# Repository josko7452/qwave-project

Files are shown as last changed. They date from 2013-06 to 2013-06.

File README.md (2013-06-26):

QWave-project
=============

Working FPGA development board with USB 2.0 interface and DSO module (125MHz analog dual channel with 16bit logic analyzer)
Although hadware was implemented it is not thoroughly tested, especially analog part is not intented as ready to build kit, it is inteded for hackers and people who are wiling to play around to get it working.

# Project parts
* **hardware** design sources of FPGA developement board and DSO module in eagle
* **firmware** sources of FPGA firmware in MyHDL and translated VHDL Xinix ISE project directory
* **software** sources of Qt based DSO sampling software

# Preview
## FPGA dev board and DSO module (dimensions 10x4cm):
-FPGA board and DSO module
## Software
[Screenshot gallery](http://imgur.com/a/RICwH#0)

#Schematics
[Link to PDF](https://www.dropbox.com/sh/cy4ldah24slzdpa/zRzbHfkyo1)

#Details:
## FPGA board:
### What works:
* FPGA programming and 3.3V logic interface and FT245 Sync interface (USB 2.0 speed)

### TODO:
* Direct USB programming of FPGA flash - need to use JTAG and Xilinx USB Platform Cable for programming

## Analog (DSO module) board:
### What works:
* DSO functionality

### What was not tested:
* Logic analyzer on anything faster than few kHz
* Compensation of analog input

### TODO:
* Eliminating noise on analog circuits

## Firmware
### TODO:
* Fix trigger
* Add selectable trigger holdoff
* Do not insert trigger in single-shot mode

## Software
### TODO:
* Better performance
* Make more user-friendly selection of trigger
* Add exact voltage meter

## For hackers/ee guys and developers:
See HACKING.md

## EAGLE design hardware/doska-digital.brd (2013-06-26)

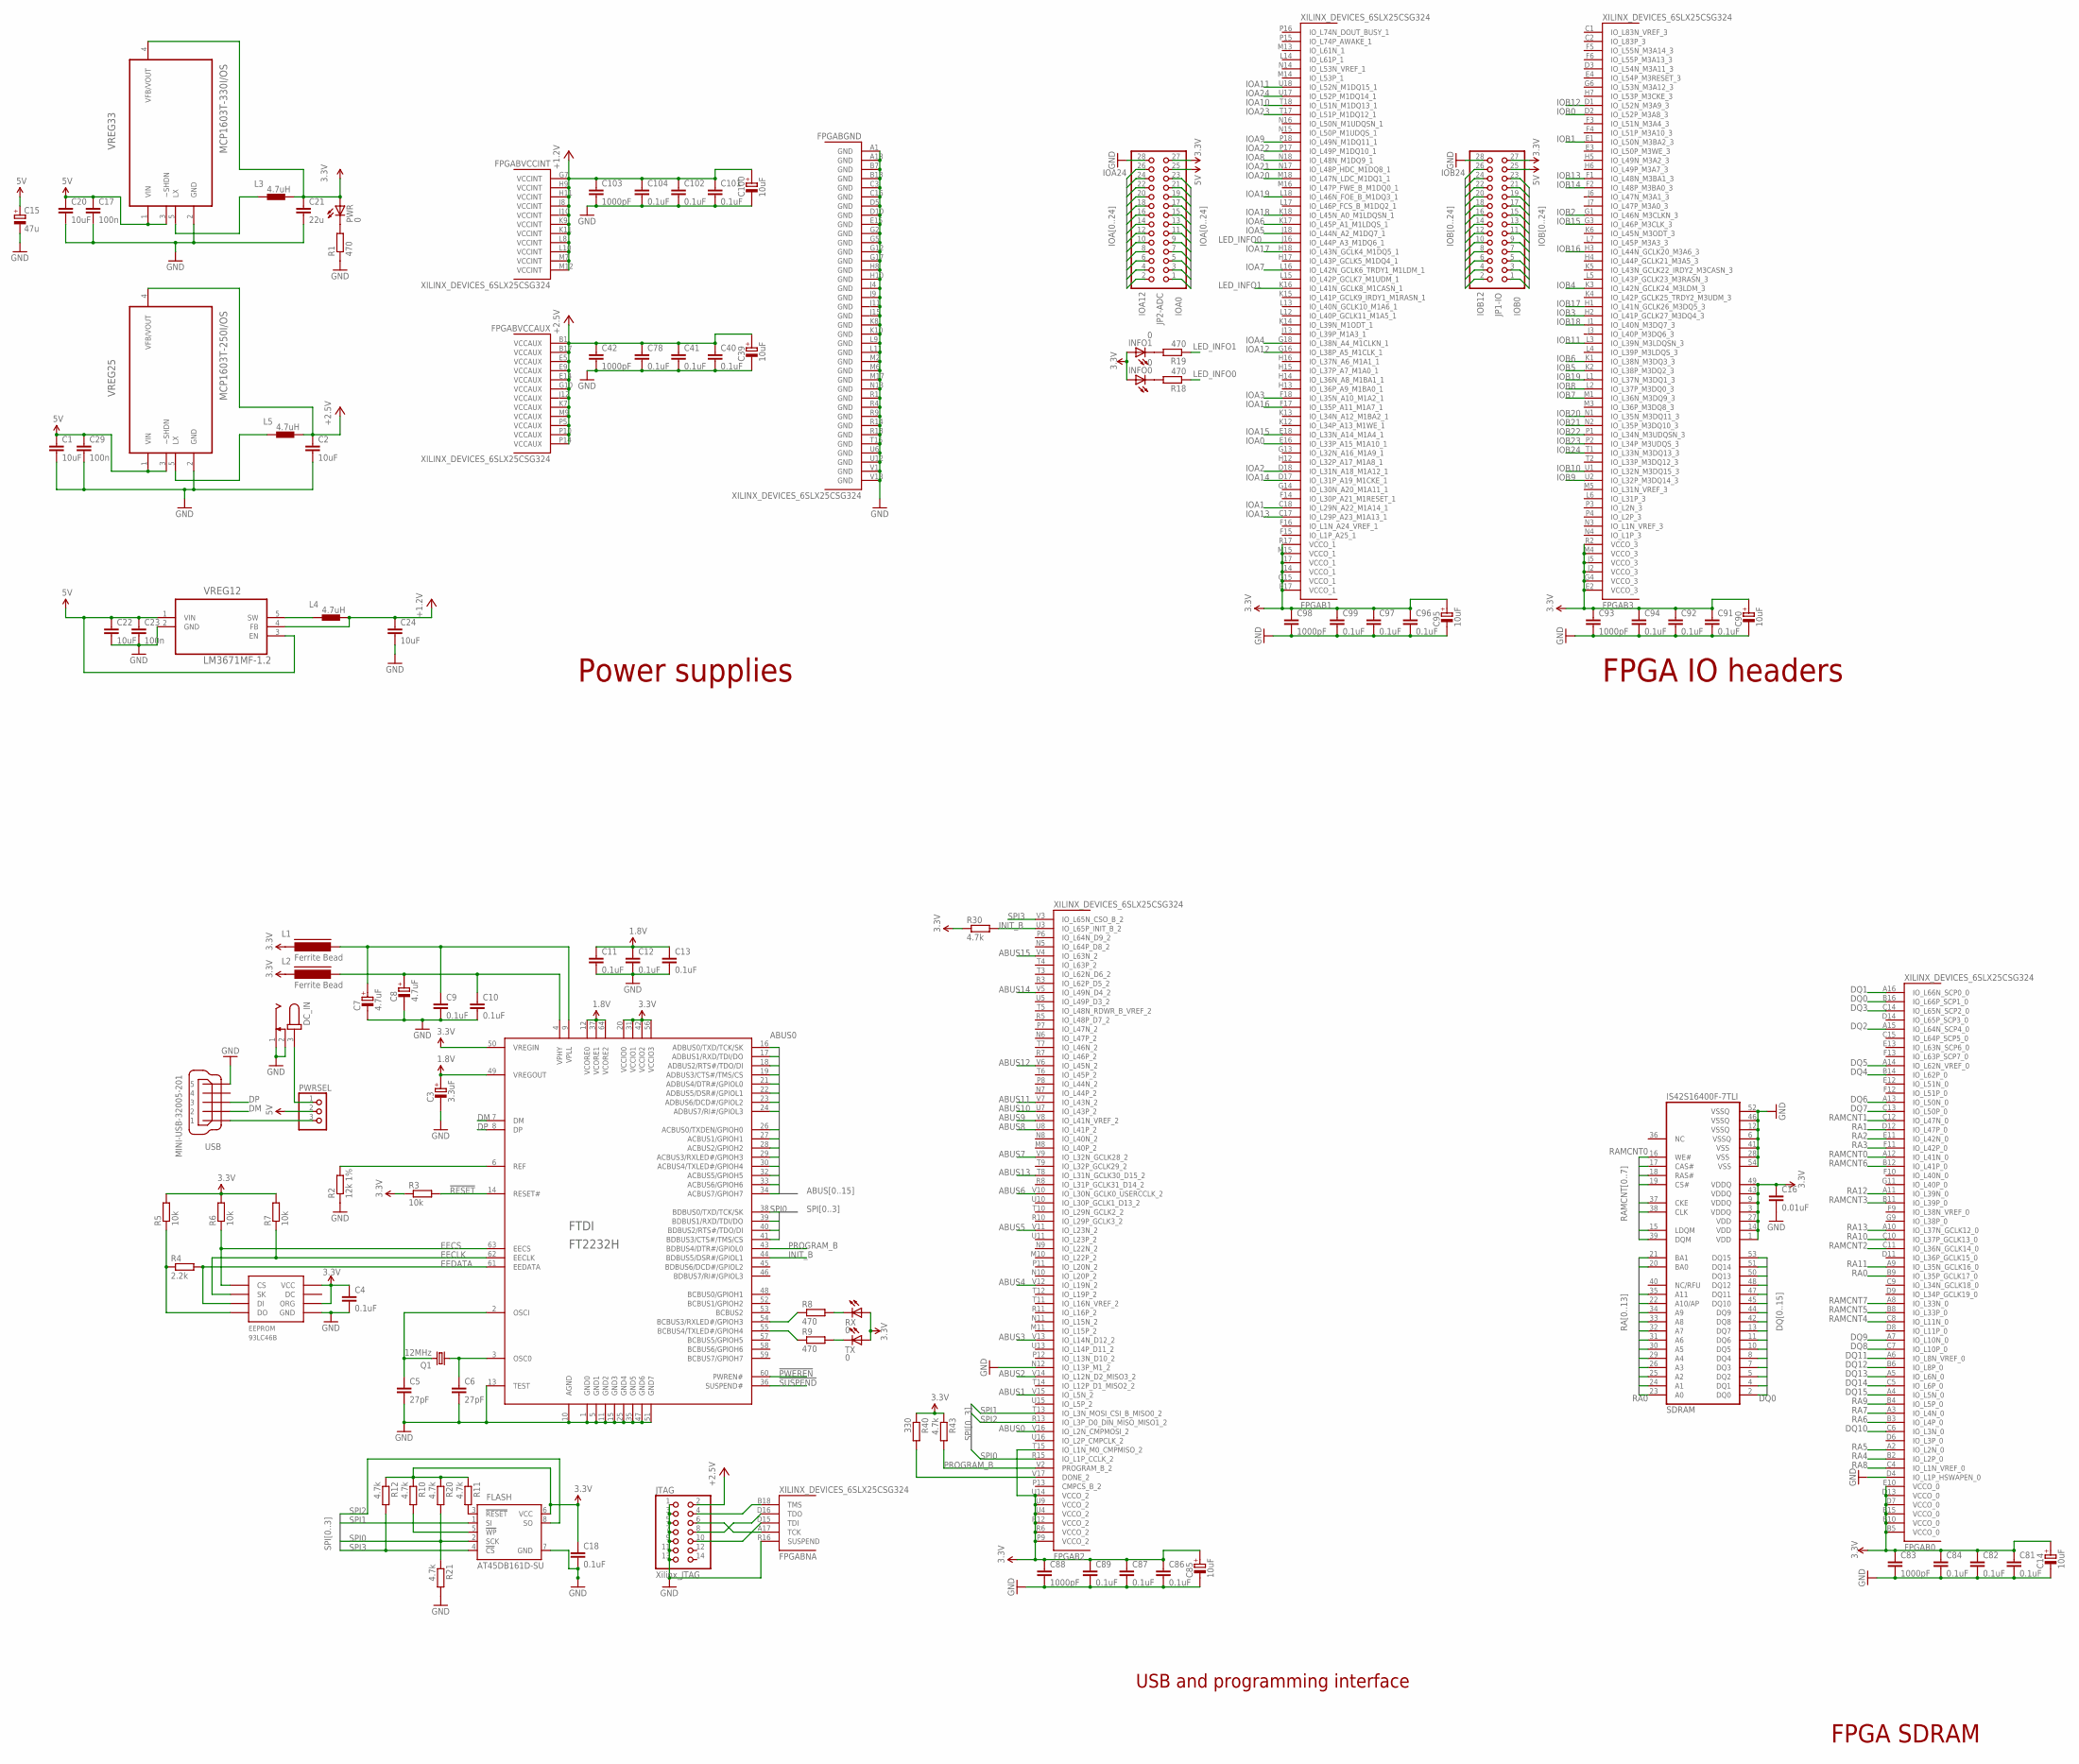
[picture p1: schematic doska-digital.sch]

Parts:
C1, C2, C20, C22, C24: 10uF; C805
C3: 3.3uF; CAPMP3216X180N
C4, C13, C18: 0.1uF; C805
C5, C6: 27pF; C805
C7, C8: 4.7uF; CAPMP3216X180N
C9, C10, C11, C12, C40, C41, C78, C81, C82, C84, C86, C87, C89, C91, C92, C94, C96, C97, C99, C101, C102, C104: 0.1uF; C603
C14, C39, C85, C90, C95, C100: 10uF; CAPMP3216X180N
C15: 47u; RCL_E2-5
C16: 0.01uF; C805
C17, C23, C29: 100n; C805
C21: 22u; C805
C42, C83, C88, C93, C98, C103: 1000pF; C603
DC_IN: CON-JACK_JACK-PLUG1; CON-JACK_SPC4078
EEPROM: 93LC46B; SOIC8
FLASH: AT45DB161D-SU; 8S2
FPGA: XILINX_DEVICES_6SLX25CSG324; XILINX_DEVICES_CS324
FTDI: FT2232H; LQFP64
INFO0, INFO1: 0; CHIPLED_1206
JP1-IO, JP2-ADC: PINHEAD_PINHD-2X14; PINHEAD_2X14
JTAG: Xilinx_JTAG; PINHEAD_2X07
L1, L2: Ferrite Bead; FB805
L3, L4, L5: 4.7uH; SMT43
PWR: 0; CHIPLED_1206
PWRSEL: PINHEAD_PINHD-1X3; PINHEAD_1X03
Q1: 12MHz; CTS406
R1, R8, R9, R18, R19: 470; R805
R2: 12k 1%; R603
R3, R5, R6, R7: 10k; R805
R4: 2.2k; R805
R10, R11, R12: 4.7k; R805
R20, R21, R30, R43: 4.7k; R603
R40: 330; R603
RX: 0; CHIPLED_1206
SDRAM: IS42S16400F-7TLI; TSOP54
TX: 0; CHIPLED_1206
USB: MINI-USB-32005-201; 32005-201
VREG12: LM3671MF-1.2; SOT95P284X122-5N
VREG25: MCP1603T-250I/OS; SOT95P280X110-5N
VREG33: MCP1603T-330I/OS; SOT95P280X110-5N

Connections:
1.8V: C3.+, C11.1, C12.1, C13.1, FTDI.12 (VCORE0), FTDI.37 (VCORE1), FTDI.49 (VREGOUT), FTDI.64 (VCORE2)
3.3V: C4.1, C14.+, C16.1, C18.1, C21.1, C81.1, C82.1, C83.1, C84.1, C85.+, C86.1, C87.1, C88.1, C89.1, C90.+, C91.1, C92.1, C93.1, C94.1, C95.+, C96.1, C97.1, C98.1, C99.1, EEPROM.6 (ORG), EEPROM.8 (VCC), FLASH.6 (VCC), FPGA.B5 (VCCO_0), FPGA.B10 (VCCO_0), FPGA.B15 (VCCO_0), FPGA.D7 (VCCO_0), FPGA.D13 (VCCO_0), FPGA.E2 (VCCO_3), FPGA.E10 (VCCO_0), FPGA.E17 (VCCO_1), FPGA.G4 (VCCO_3), FPGA.G15 (VCCO_1), FPGA.J2 (VCCO_3), FPGA.J5 (VCCO_3), FPGA.J14 (VCCO_1), FPGA.J17 (VCCO_1), FPGA.M4 (VCCO_3), FPGA.M15 (VCCO_1), FPGA.P9 (VCCO_2), FPGA.R2 (VCCO_3), FPGA.R6 (VCCO_2), FPGA.R12 (VCCO_2), FPGA.R17 (VCCO_1), FPGA.T15 (IO_L1N_M0_CMPMISO_2), FPGA.U4 (VCCO_2), FPGA.U9 (VCCO_2), FPGA.U14 (VCCO_2), FTDI.20 (VCCIO0), FTDI.31 (VCCIO1), FTDI.42 (VCCIO2), FTDI.50 (VREGIN), FTDI.56 (VCCIO3), INFO0.A, INFO1.A, JP1-IO.27, JP2-ADC.27, L1.2, L2.2, L3.P$1 (1), PWR.A, R3.1, R5.2, R6.2, R7.2, R10.1, R11.1, R12.1, R20.1, R30.1, R40.1, R43.1, RX.A, SDRAM.1 (VDD), SDRAM.3 (VDDQ), SDRAM.9 (VDDQ), SDRAM.14 (VDD), SDRAM.27 (VDD), SDRAM.43 (VDDQ), SDRAM.49 (VDDQ), TX.A, VREG33.4 (VFB/VOUT)
5V: C1.1, C15.+, C17.1, C20.1, C22.1, C23.1, C29.1, JP1-IO.25, JP2-ADC.25, PWRSEL.2, VREG12.1 (VIN), VREG12.3 (EN), VREG25.1 (VIN), VREG25.3 (~SHDN), VREG33.1 (VIN), VREG33.3 (~SHDN)
!PWEREN: FTDI.60 (PWREN#)
!RESET: FTDI.14 (RESET#), R3.2
!SUSPEND: FTDI.36 (SUSPEND#)
+1.2V: C24.1, C100.+, C101.1, C102.1, C103.1, C104.1, FPGA.G7 (VCCINT), FPGA.H9 (VCCINT), FPGA.H11 (VCCINT), FPGA.J8 (VCCINT), FPGA.J10 (VCCINT), FPGA.K9 (VCCINT), FPGA.K11 (VCCINT), FPGA.L8 (VCCINT), FPGA.L10 (VCCINT), FPGA.M7 (VCCINT), FPGA.M12 (VCCINT), L4.P$1 (1), VREG12.4 (FB)
+2.5V: C2.1, C39.+, C40.1, C41.1, C42.1, C78.1, FPGA.B1 (VCCAUX), FPGA.B17 (VCCAUX), FPGA.E5 (VCCAUX), FPGA.E9 (VCCAUX), FPGA.E14 (VCCAUX), FPGA.G10 (VCCAUX), FPGA.J12 (VCCAUX), FPGA.K7 (VCCAUX), FPGA.M9 (VCCAUX), FPGA.P5 (VCCAUX), FPGA.P10 (VCCAUX), FPGA.P14 (VCCAUX), JTAG.2, L5.P$1 (1), VREG25.4 (VFB/VOUT)
ABUS0: FPGA.V16 (IO_L2N_CMPMOSI_2), FTDI.16 (ADBUS0/TXD/TCK/SK)
ABUS1: FPGA.V15 (IO_L5N_2), FTDI.17 (ADBUS1/RXD/TDI/DO)
ABUS2: FPGA.V14 (IO_L12N_D2_MISO3_2), FTDI.18 (ADBUS2/RTS#/TDO/DI)
ABUS3: FPGA.V13 (IO_L14N_D12_2), FTDI.19 (ADBUS3/CTS#/TMS/CS)
ABUS4: FPGA.V12 (IO_L19N_2), FTDI.21 (ADBUS4/DTR#/GPIOL0)
ABUS5: FPGA.V11 (IO_L23N_2), FTDI.22 (ADBUS5/DSR#/GPIOL1)
ABUS6: FPGA.V10 (IO_L30N_GCLK0_USERCCLK_2), FTDI.23 (ADBUS6/DCD#/GPIOL2)
ABUS7: FPGA.V9 (IO_L32N_GCLK28_2), FTDI.24 (ADBUS7/RI#/GPIOL3)
ABUS8: FPGA.U8 (IO_L41P_2), FTDI.26 (ACBUS0/TXDEN/GPIOH0)
ABUS9: FPGA.V8 (IO_L41N_VREF_2), FTDI.27 (ACBUS1/GPIOH1)
ABUS10: FPGA.U7 (IO_L43P_2), FTDI.28 (ACBUS2/GPIOH2)
ABUS11: FPGA.V7 (IO_L43N_2), FTDI.29 (ACBUS3/RXLED#/GPIOH3)
ABUS12: FPGA.V6 (IO_L45N_2), FTDI.30 (ACBUS4/TXLED#/GPIOH4)
ABUS13: FPGA.T8 (IO_L31N_GCLK30_D15_2), FTDI.32 (ACBUS5/GPIOH5)
ABUS14: FPGA.V5 (IO_L49N_D4_2), FTDI.33 (ACBUS6/GPIOH6)
ABUS15: FPGA.V4 (IO_L63N_2), FTDI.34 (ACBUS7/GPIOH7)
DM: FTDI.7 (DM), USB.2
DP: FTDI.8 (DP), USB.3
DQ0: FPGA.B16 (IO_L66P_SCP1_0), SDRAM.2 (DQ0)
DQ1: FPGA.A16 (IO_L66N_SCP0_0), SDRAM.4 (DQ1)
DQ2: FPGA.A15 (IO_L64N_SCP4_0), SDRAM.5 (DQ2)
DQ3: FPGA.C14 (IO_L65N_SCP2_0), SDRAM.7 (DQ3)
DQ4: FPGA.B14 (IO_L62P_0), SDRAM.8 (DQ4)
DQ5: FPGA.A14 (IO_L62N_VREF_0), SDRAM.10 (DQ5)
DQ6: FPGA.A13 (IO_L50N_0), SDRAM.11 (DQ6)
DQ7: FPGA.C13 (IO_L50P_0), SDRAM.13 (DQ7)
DQ8: FPGA.C7 (IO_L10P_0), SDRAM.42 (DQ8)
DQ9: FPGA.A7 (IO_L10N_0), SDRAM.44 (DQ9)
DQ10: FPGA.C6 (IO_L3N_0), SDRAM.45 (DQ10)
DQ11: FPGA.A6 (IO_L8N_VREF_0), SDRAM.47 (DQ11)
DQ12: FPGA.B6 (IO_L8P_0), SDRAM.48 (DQ12)
DQ13: FPGA.A5 (IO_L6N_0), SDRAM.50 (DQ13)
DQ14: FPGA.C5 (IO_L6P_0), SDRAM.51 (DQ14)
DQ15: FPGA.A4 (IO_L5N_0), SDRAM.53 (DQ15)
EECLK: EEPROM.2 (SK), FTDI.62 (EECLK), R7.1
EECS: EEPROM.1 (CS), FTDI.63 (EECS), R6.1
EEDATA: EEPROM.3 (DI), FTDI.61 (EEDATA), R4.2
GND: C1.2, C2.2, C3.-, C4.2, C5.2, C6.2, C7.-, C8.-, C9.2, C10.2, C11.2, C12.2, C13.2, C14.-, C15.-, C16.2, C17.2, C18.2, C20.2, C21.2, C22.2, C23.2, C24.2, C29.2, C39.-, C40.2, C41.2, C42.2, C78.2, C81.2, C82.2, C83.2, C84.2, C85.-, C86.2, C87.2, C88.2, C89.2, C90.-, C91.2, C92.2, C93.2, C94.2, C95.-, C96.2, C97.2, C98.2, C99.2, C100.-, C101.2, C102.2, C103.2, C104.2, DC_IN.1, DC_IN.2, EEPROM.5 (GND), FLASH.7 (GND), FPGA.A1 (GND), FPGA.A18 (GND), FPGA.B7 (GND), FPGA.B13 (GND), FPGA.C3 (GND), FPGA.C16 (GND), FPGA.D4 (IO_L1P_HSWAPEN_0), FPGA.D5 (GND), FPGA.D10 (GND), FPGA.E15 (GND), FPGA.G2 (GND), FPGA.G5 (GND), FPGA.G12 (GND), FPGA.G17 (GND), FPGA.H8 (GND), FPGA.H10 (GND), FPGA.J4 (GND), FPGA.J9 (GND), FPGA.J11 (GND), FPGA.J15 (GND), FPGA.K8 (GND), FPGA.K10 (GND), FPGA.L9 (GND), FPGA.L11 (GND), FPGA.M2 (GND), FPGA.M6 (GND), FPGA.M17 (GND), FPGA.N12 (IO_L13P_M1_2), FPGA.N13 (GND), FPGA.R1 (GND), FPGA.R4 (GND), FPGA.R9 (GND), FPGA.R14 (GND), FPGA.R16 (SUSPEND), FPGA.R18 (GND), FPGA.T16 (GND), FPGA.U6 (GND), FPGA.U12 (GND), FPGA.V1 (GND), FPGA.V18 (GND), FTDI.1 (GND0), FTDI.5 (GND1), FTDI.10 (AGND), FTDI.11 (GND2), FTDI.13 (TEST), FTDI.15 (GND3), FTDI.25 (GND4), FTDI.35 (GND5), FTDI.47 (GND6), FTDI.51 (GND7), JP1-IO.28, JP2-ADC.28, JTAG.1, JTAG.3, JTAG.5, JTAG.7, JTAG.9, JTAG.11, JTAG.13, R1.1, R2.1, R21.2, SDRAM.6 (VSSQ), SDRAM.12 (VSSQ), SDRAM.28 (VSS), SDRAM.41 (VSS), SDRAM.46 (VSSQ), SDRAM.52 (VSSQ), SDRAM.54 (VSS), USB.5, VREG12.2 (GND), VREG25.2 (GND), VREG33.2 (GND)
INIT_B: FPGA.U3 (IO_L65P_INIT_B_2), FTDI.44 (BDBUS5/DSR#/GPIOL1), R30.2
IOA0: FPGA.E16 (IO_L33P_A15_M1A10_1), JP2-ADC.1
IOA1: FPGA.C18 (IO_L29N_A22_M1A14_1), JP2-ADC.3
IOA2: FPGA.D18 (IO_L31N_A18_M1A12_1), JP2-ADC.5
IOA3: FPGA.F18 (IO_L35N_A10_M1A2_1), JP2-ADC.7
IOA4: FPGA.G18 (IO_L38N_A4_M1CLKN_1), JP2-ADC.9
IOA5: FPGA.J18 (IO_L44N_A2_M1DQ7_1), JP2-ADC.11
IOA6: FPGA.K17 (IO_L45P_A1_M1LDQS_1), JP2-ADC.13
IOA7: FPGA.L16 (IO_L42N_GCLK6_TRDY1_M1LDM_1), JP2-ADC.15
IOA8: FPGA.N18 (IO_L48N_M1DQ9_1), JP2-ADC.17
IOA9: FPGA.P18 (IO_L49N_M1DQ11_1), JP2-ADC.19
IOA10: FPGA.T18 (IO_L51N_M1DQ13_1), JP2-ADC.21
IOA11: FPGA.U18 (IO_L52N_M1DQ15_1), JP2-ADC.23
IOA12: FPGA.G16 (IO_L38P_A5_M1CLK_1), JP2-ADC.2
IOA13: FPGA.C17 (IO_L29P_A23_M1A13_1), JP2-ADC.4
IOA14: FPGA.D17 (IO_L31P_A19_M1CKE_1), JP2-ADC.6
IOA15: FPGA.E18 (IO_L33N_A14_M1A4_1), JP2-ADC.8
IOA16: FPGA.F17 (IO_L35P_A11_M1A7_1), JP2-ADC.10
IOA17: FPGA.H18 (IO_L43N_GCLK4_M1DQ5_1), JP2-ADC.12
IOA18: FPGA.K18 (IO_L45N_A0_M1LDQSN_1), JP2-ADC.14
IOA19: FPGA.L18 (IO_L46N_FOE_B_M1DQ3_1), JP2-ADC.16
IOA20: FPGA.M18 (IO_L47N_LDC_M1DQ1_1), JP2-ADC.18
IOA21: FPGA.N17 (IO_L48P_HDC_M1DQ8_1), JP2-ADC.20
IOA22: FPGA.P17 (IO_L49P_M1DQ10_1), JP2-ADC.22
IOA23: FPGA.T17 (IO_L51P_M1DQ12_1), JP2-ADC.24
IOA24: FPGA.U17 (IO_L52P_M1DQ14_1), JP2-ADC.26
IOB0: FPGA.D2 (IO_L52P_M3A8_3), JP1-IO.1
IOB1: FPGA.E1 (IO_L50N_M3BA2_3), JP1-IO.3
IOB2: FPGA.G1 (IO_L46N_M3CLKN_3), JP1-IO.5
IOB3: FPGA.H2 (IO_L41P_GCLK27_M3DQ4_3), JP1-IO.7
IOB4: FPGA.K3 (IO_L42N_GCLK24_M3LDM_3), JP1-IO.9
IOB5: FPGA.K2 (IO_L38P_M3DQ2_3), JP1-IO.11
IOB6: FPGA.K1 (IO_L38N_M3DQ3_3), JP1-IO.13
IOB7: FPGA.M1 (IO_L36N_M3DQ9_3), JP1-IO.15
IOB8: FPGA.L2 (IO_L37P_M3DQ0_3), JP1-IO.17
IOB9: FPGA.U2 (IO_L32P_M3DQ14_3), JP1-IO.19
IOB10: FPGA.U1 (IO_L32N_M3DQ15_3), JP1-IO.21
IOB11: FPGA.L3 (IO_L39N_M3LDQSN_3), JP1-IO.23
IOB12: FPGA.D1 (IO_L52N_M3A9_3), JP1-IO.2
IOB13: FPGA.F1 (IO_L48N_M3BA1_3), JP1-IO.4
IOB14: FPGA.F2 (IO_L48P_M3BA0_3), JP1-IO.6
IOB15: FPGA.G3 (IO_L46P_M3CLK_3), JP1-IO.8
IOB16: FPGA.H3 (IO_L44N_GCLK20_M3A6_3), JP1-IO.10
IOB17: FPGA.H1 (IO_L41N_GCLK26_M3DQ5_3), JP1-IO.12
IOB18: FPGA.J1 (IO_L40N_M3DQ7_3), JP1-IO.14
IOB19: FPGA.L1 (IO_L37N_M3DQ1_3), JP1-IO.16
IOB20: FPGA.N1 (IO_L35N_M3DQ11_3), JP1-IO.18
IOB21: FPGA.N2 (IO_L35P_M3DQ10_3), JP1-IO.20
IOB22: FPGA.P1 (IO_L34N_M3UDQSN_3), JP1-IO.22
IOB23: FPGA.P2 (IO_L34P_M3UDQS_3), JP1-IO.24
IOB24: FPGA.T1 (IO_L33N_M3DQ13_3), JP1-IO.26
LED_INFO0: FPGA.J16 (IO_L44P_A3_M1DQ6_1), R18.1
LED_INFO1: FPGA.K16 (IO_L41N_GCLK8_M1CASN_1), R19.1
unnamed: PWR.C, R1.2
unnamed: R8.2, RX.C
unnamed: R9.2, TX.C
unnamed: FTDI.6 (REF), R2.2
unnamed: FLASH.5 (!WP), R10.2
unnamed: FLASH.3 (!RESET), R11.2
unnamed: C5.1, FTDI.2 (OSCI), Q1.3 (2)
unnamed: C6.1, FTDI.3 (OSC0), Q1.1
unnamed: L4.P$2 (2), VREG12.5 (SW)
unnamed: INFO0.C, R18.2
unnamed: L5.P$2 (2), VREG25.5 (LX)
unnamed: PWRSEL.3, USB.1
unnamed: L3.P$2 (2), VREG33.5 (LX)
unnamed: DC_IN.3, PWRSEL.1
unnamed: INFO1.C, R19.2
unnamed: FTDI.55 (BCBUS4/TXLED#/GPIOH4), R9.1
unnamed: FTDI.54 (BCBUS3/RXLED#/GPIOH3), R8.1
unnamed: FPGA.V17 (DONE_2), R40.2
unnamed: FPGA.B18 (TMS), JTAG.4
unnamed: FPGA.A17 (TCK), JTAG.6
unnamed: EEPROM.4 (DO), R4.1, R5.1
unnamed: FPGA.D16 (TDO), JTAG.8
unnamed: FPGA.D15 (TDI), JTAG.10
unnamed: C7.+, C9.1, FTDI.9 (VPLL), L1.1
unnamed: C8.+, C10.1, FTDI.4 (VPHY), L2.1
PROGRAM_B: FPGA.V2 (PROGRAM_B_2), FTDI.43 (BDBUS4/DTR#/GPIOL0), R43.2
RA0: FPGA.B9 (IO_L35P_GCLK17_0), SDRAM.23 (A0)
RA1: FPGA.D12 (IO_L47P_0), SDRAM.24 (A1)
RA2: FPGA.E11 (IO_L42N_0), SDRAM.25 (A2)
RA3: FPGA.F11 (IO_L42P_0), SDRAM.26 (A3)
RA4: FPGA.B2 (IO_L2P_0), SDRAM.29 (A4)
RA5: FPGA.A2 (IO_L2N_0), SDRAM.30 (A5)
RA6: FPGA.B3 (IO_L4P_0), SDRAM.31 (A6)
RA7: FPGA.A3 (IO_L4N_0), SDRAM.32 (A7)
RA8: FPGA.C4 (IO_L1N_VREF_0), SDRAM.33 (A8)
RA9: FPGA.B4 (IO_L5P_0), SDRAM.34 (A9)
RA10: FPGA.C10 (IO_L37P_GCLK13_0), SDRAM.22 (A10/AP)
RA11: FPGA.A9 (IO_L35N_GCLK16_0), SDRAM.35 (A11)
RA12: FPGA.A11 (IO_L39N_0), SDRAM.20 (BA0)
RA13: FPGA.A10 (IO_L37N_GCLK12_0), SDRAM.21 (BA1)
RAMCNT0: FPGA.A12 (IO_L41N_0), SDRAM.16 (WE#)
RAMCNT1: FPGA.C12 (IO_L47N_0), SDRAM.17 (CAS#)
RAMCNT2: FPGA.C11 (IO_L36N_GCLK14_0), SDRAM.18 (RAS#)
RAMCNT3: FPGA.B11 (IO_L39P_0), SDRAM.19 (CS#)
RAMCNT4: FPGA.C8 (IO_L11N_0), SDRAM.37 (CKE)
RAMCNT5: FPGA.B8 (IO_L33P_0), SDRAM.38 (CLK)
RAMCNT6: FPGA.B12 (IO_L41P_0), SDRAM.15 (LDQM)
RAMCNT7: FPGA.A8 (IO_L33N_0), SDRAM.39 (DQM)
SPI0: FLASH.2 (SCK), FPGA.R15 (IO_L1P_CCLK_2), FTDI.38 (BDBUS0/TXD/TCK/SK), R20.2, R21.1
SPI1: FLASH.1 (SI), FPGA.T13 (IO_L3N_MOSI_CSI_B_MISO0_2), FTDI.39 (BDBUS1/RXD/TDI/DO)
SPI2: FLASH.8 (SO), FPGA.R13 (IO_L3P_D0_DIN_MISO_MISO1_2), FTDI.40 (BDBUS2/RTS#/TDO/DI)
SPI3: FLASH.4 (!CS), FPGA.V3 (IO_L65N_CSO_B_2), FTDI.41 (BDBUS3/CTS#/TMS/CS), R12.2

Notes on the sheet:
FPGA IO headers
FPGA SDRAM
Power supplies
USB and programming interface

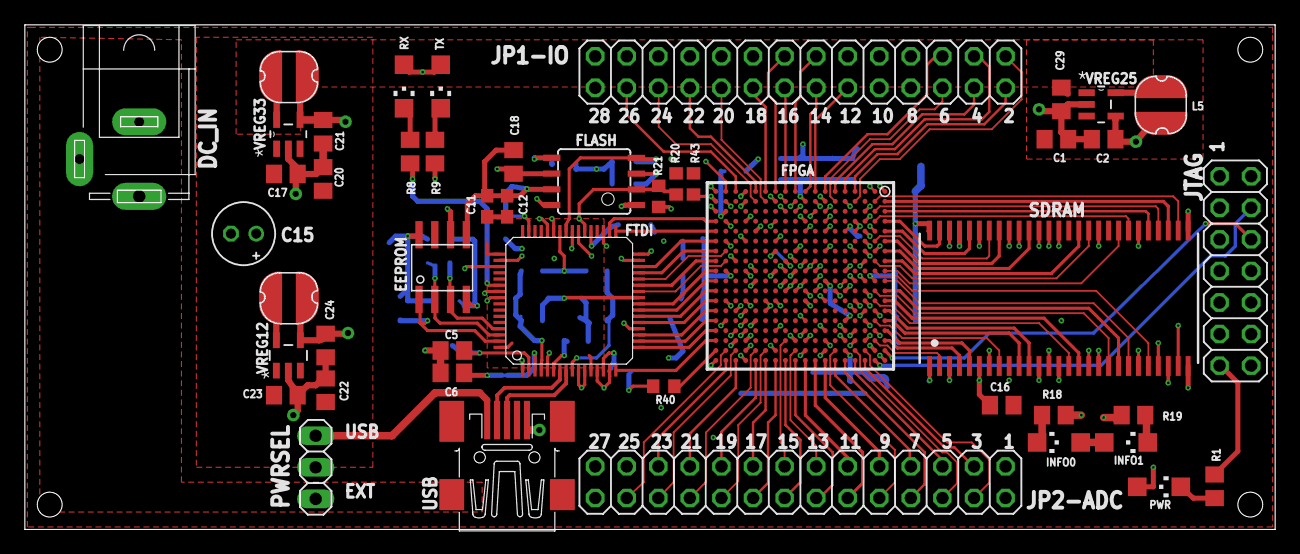
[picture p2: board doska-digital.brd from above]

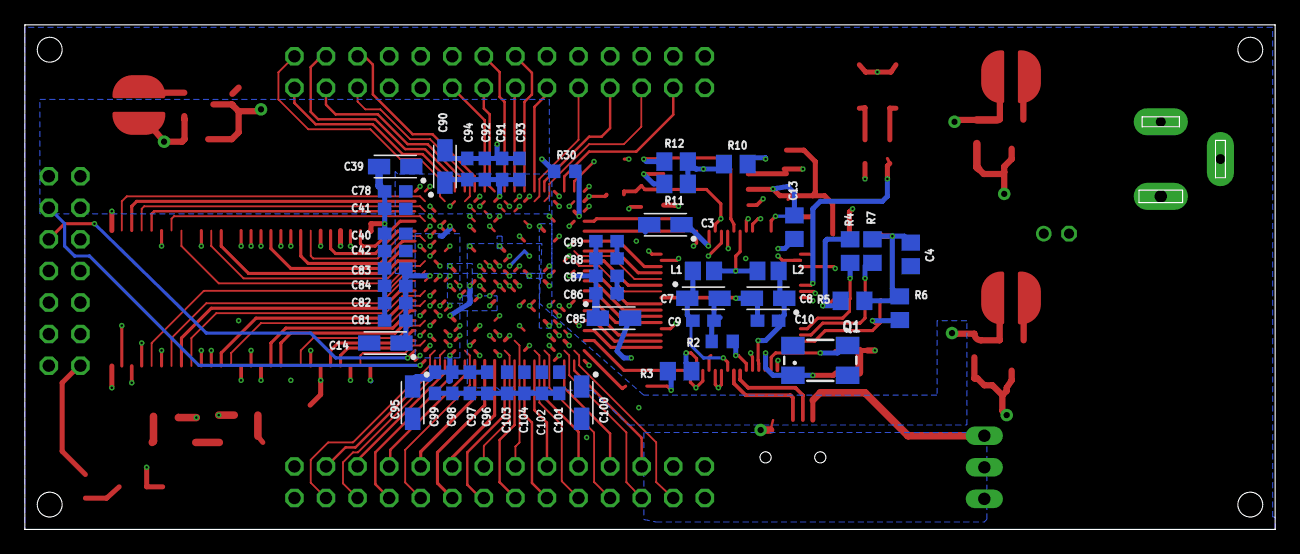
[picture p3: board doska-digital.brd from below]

Board: 4 copper layers, 100.6 x 40.6 mm, 97 parts (50 on the bottom side), 149 nets.

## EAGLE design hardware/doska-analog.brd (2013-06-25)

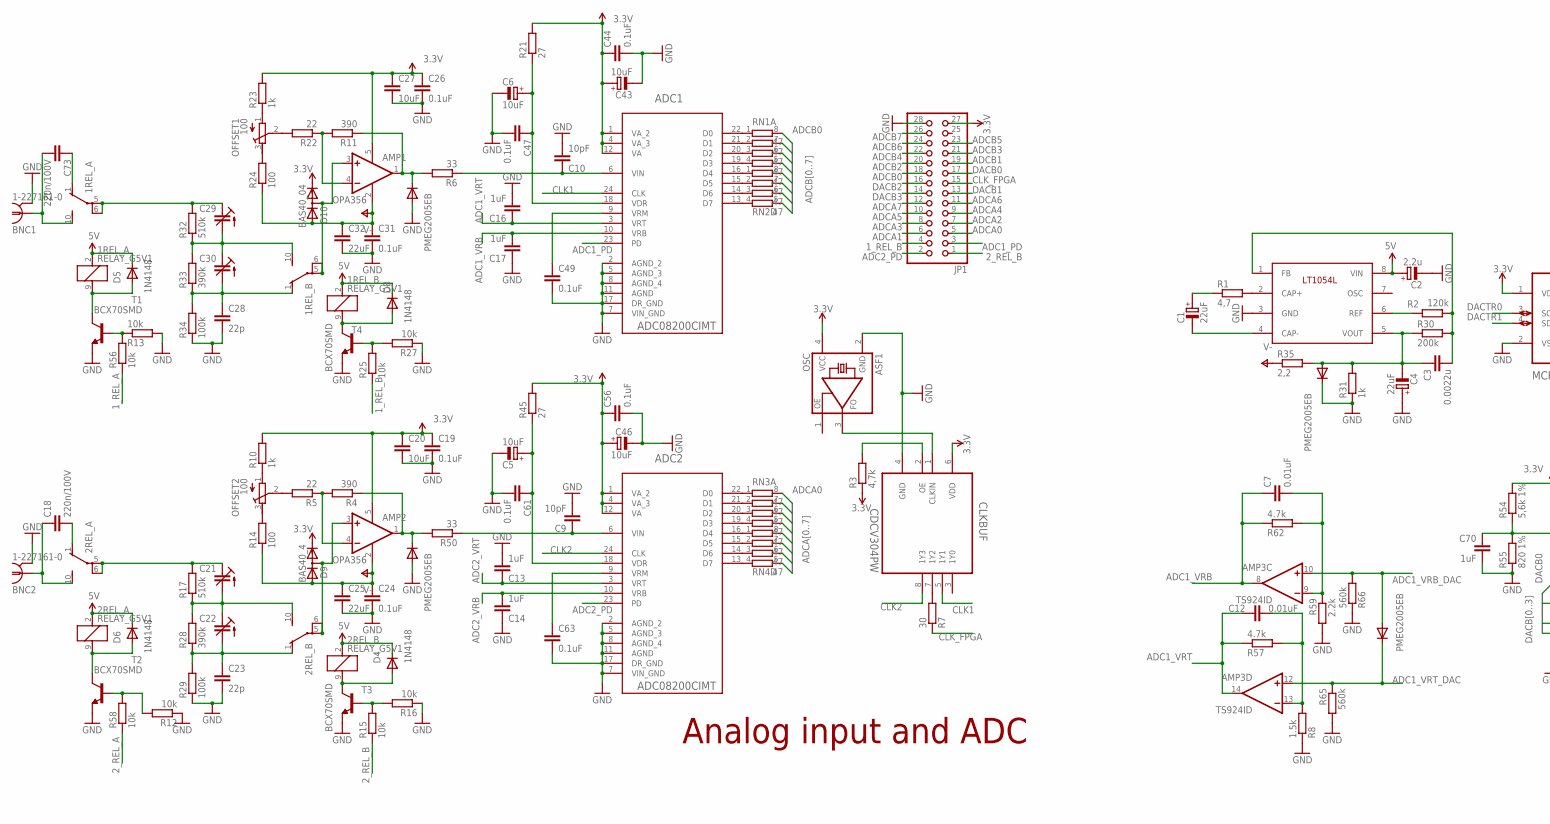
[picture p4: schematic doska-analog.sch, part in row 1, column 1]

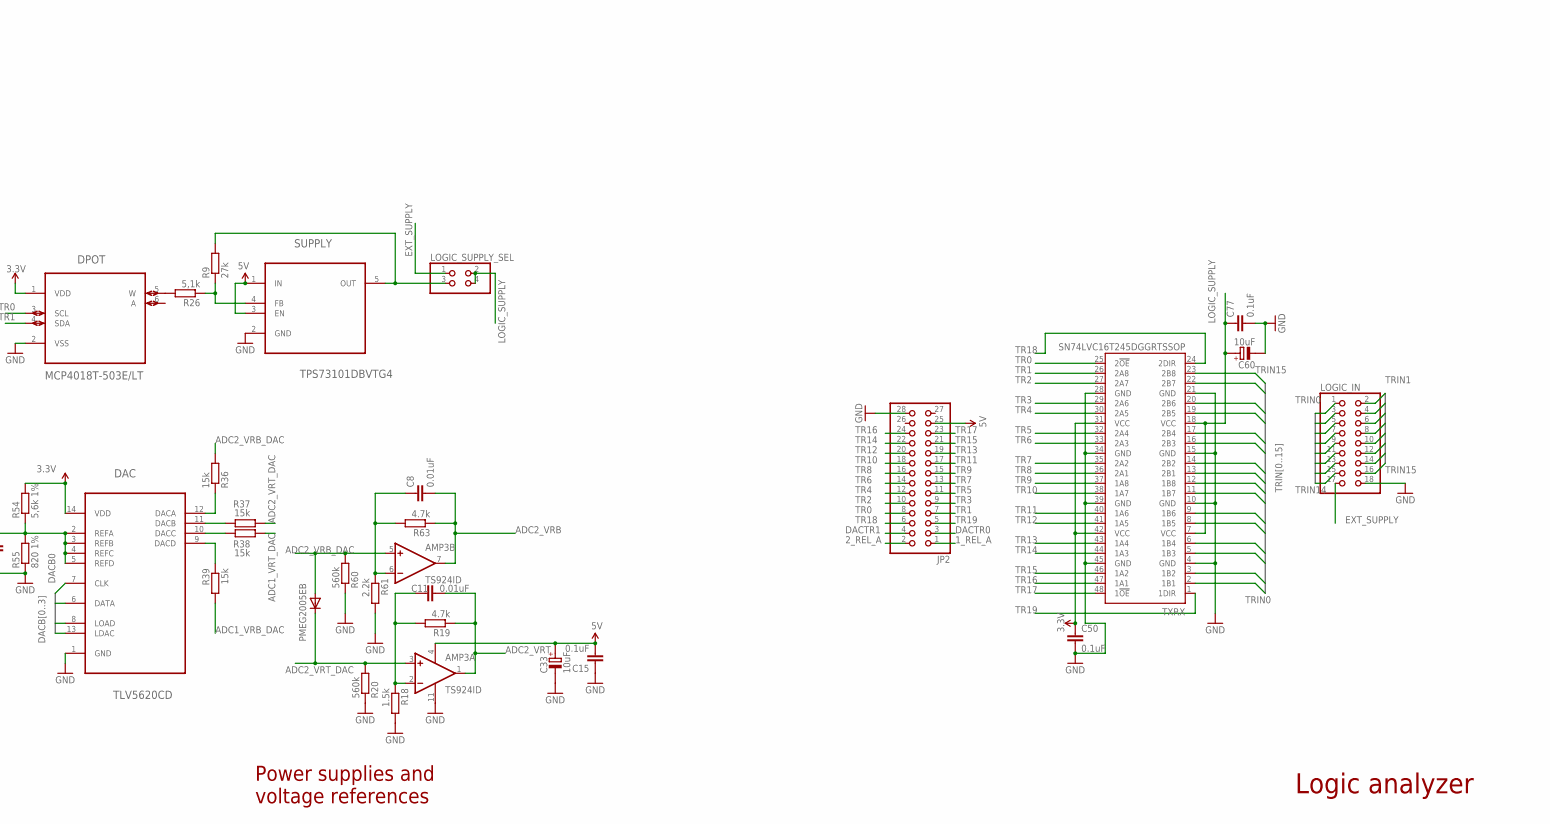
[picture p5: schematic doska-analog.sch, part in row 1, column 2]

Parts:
1REL_A, 2REL_A: RELAY_G5V1
1REL_B, 2REL_B: RELAY_G5V1; MPN G5V-1-DC24
ADC1, ADC2: ADC08200CIMT; SOP65P640X110-24N
AMP1, AMP2: OPA356; SOT23-5
AMP3: TS924ID; SOIC127P600X175-14N
BNC1, BNC2: 1-227161-0; AMP_227161
C1, C4: 22uF; CAPMP3528X210N
C2: 2.2u; CAPMP3216X180N
C3: 0.0022u; C603
C5, C6, C33, C43, C46, C60: 10uF; CAPMP3216X180N
C7, C8, C11, C12: 0.01uF; C603
C9, C10: 10pF; C603
C13, C14, C16, C17, C70: 1uF; C603
C15, C50, C77: 0.1uF; C805
C18, C73: 220n/100V; C1206
C19, C24, C26, C31, C44, C47, C49, C56, C61, C63: 0.1uF; C603
C20, C27: 10uF; C805
C21, C22, C29, C30: TZB4Z100AB10R00; CTRIMTZB4
C23, C28: 22p; C603
C25, C32: 22uF; C805
CLKBUF: CDCV304PW; SOP65P640X120-8N
D1, D2, D3, D7, D11: PMEG2005EB; SOD523
D4, D5, D6, D8: 1N4148; SOD323-R
D9: BAS40_4; SOT23
D10: BAS40_04; SOT23
DAC: TLV5620CD; SOIC127P600X175-14N
DPOT: MCP4018T-503E/LT; SOT65P210X110-6N
JP1, JP2: PINHEAD_PINHD-2X14; PINHEAD_2X14
LOGIC_IN: PINHEAD_PINHD-2X9; PINHEAD_2X09
LOGIC_SUPPLY_SEL: PINHEAD_PINHD-2X2; PINHEAD_2X02
OFFSET1, OFFSET2: 100; RTRIMTC33
OSC: ASF1; ASF
R1: 4,7; R1206
R2: 120k; R603
R3: 4,7k; R603
R4, R11: 390; R603
R5, R22: 22; R603
R6, R50: 33; R603
R7: 30; R603
R8, R18: 1.5k; R603
R9: 27k; R603
R10, R23, R31: 1k; R603
R12, R13, R15, R16, R25, R27, R56, R58: 10k; R603
R14, R24: 100; R603
R17, R32: 510k; R805
R19, R57, R62, R63: 4.7k; R603
R20, R60, R65, R66: 560k; R603
R21, R45: 27; R603
R26: 5,1k; R603
R28, R33: 390k; R805
R29, R34: 100k; R805
R30: 200k; R603
R35: 2,2; R603
R36, R37, R38, R39: 15k; R603
R54: 5,6k 1%; R603
R55: 820 1%; R603
R59, R61: 2.2k; R603
RN1, RN2, RN3, RN4: 47; EXB38V
SUPPLY: TPS73101DBVTG4; SOT95P280X145-5N
T1, T2, T3, T4: BCX70SMD; SOT23
TXRX: SN74LVC16T245DGGRTSSOP; TSSOP48
VREG: LT1054LCS8; SO08

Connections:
1_REL_A: JP2.1, R56.1
1_REL_B: JP1.4, R25.1
2_REL_A: JP2.2, R58.1
2_REL_B: JP1.1, R15.1
3.3V: ADC1.1 (VA_2), ADC1.4 (VA_3), ADC1.12 (VA), ADC2.1 (VA_2), ADC2.4 (VA_3), ADC2.12 (VA), AMP1.5 (V+), AMP2.5 (V+), C19.1, C20.1, C26.1, C27.1, C43.+, C44.1, C46.+, C50.1, C56.1, CLKBUF.6 (VDD), D9.2 (C), D10.2 (C), DAC.14 (VDD), DPOT.1 (VDD), JP1.27, OSC.4 (VCC), R3.1, R10.2, R21.2, R23.2, R45.2, R54.2, TXRX.31 (VCC), TXRX.42 (VCC)
5V: 1REL_A.2 (1), 1REL_B.2 (1), 2REL_A.2 (1), 2REL_B.2 (1), AMP3.4 (V+), C2.+, C15.2, C33.+, D4.C, D5.C, D6.C, D8.C, JP2.25, SUPPLY.1 (IN), SUPPLY.3 (EN), VREG.8 (VIN)
ADC1_PD: ADC1.23 (PD), JP1.3
ADC1_VRB: ADC1.10 (VRB), AMP3.8 (OUT), C7.1, C17.2, R62.1
ADC1_VRB_DAC: AMP3.10 (+IN), D2.A, R39.2, R66.2
ADC1_VRB_DAC_OUT: DAC.9 (DACD), R39.1
ADC1_VRT: ADC1.3 (VRT), AMP3.14 (OUT), C12.1, C16.1, R57.1
ADC1_VRT_DAC: AMP3.12 (+IN), D2.C, R38.1, R65.1
ADC1_VRT_DAC_OUT: DAC.10 (DACC), R38.2
ADC2_PD: ADC2.23 (PD), JP1.2
ADC2_VRB: ADC2.10 (VRB), AMP3.7 (OUT), C8.2, C14.2, R63.1
ADC2_VRB_DAC: AMP3.5 (+IN), D3.A, R36.2, R60.2
ADC2_VRB_DAC_OUT: DAC.12 (DACA), R36.1
ADC2_VRT: ADC2.3 (VRT), AMP3.1 (OUT), C11.2, C13.1, R19.1
ADC2_VRT_DAC: AMP3.3 (+IN), D3.C, R20.2, R37.1
ADC2_VRT_DAC_OUT: DAC.11 (DACB), R37.2
ADCA0: JP1.5, RN3.8 (2)
ADCA1: JP1.6, RN3.7 (2)
ADCA2: JP1.7, RN3.6 (2)
ADCA3: JP1.8, RN3.5 (2)
ADCA4: JP1.9, RN4.8 (2)
ADCA5: JP1.10, RN4.7 (2)
ADCA6: JP1.11, RN4.6 (2)
ADCA7: JP1.12, RN4.5 (2)
ADCB0: JP1.18, RN1.8 (2)
ADCB1: JP1.19, RN1.7 (2)
ADCB2: JP1.20, RN1.6 (2)
ADCB3: JP1.21, RN1.5 (2)
ADCB4: JP1.22, RN2.8 (2)
ADCB5: JP1.23, RN2.7 (2)
ADCB6: JP1.24, RN2.6 (2)
ADCB7: JP1.26, RN2.5 (2)
CLK1: ADC1.24 (CLK), CLKBUF.5 (1Y1)
CLK2: ADC2.24 (CLK), CLKBUF.8 (1Y3)
CLK_FPGA: JP1.15, R7.1
DACB0: DAC.7 (CLK), JP1.17
DACB1: DAC.6 (DATA), JP1.13
DACB2: DAC.8 (LOAD), JP1.16
DACB3: DAC.13 (LDAC), JP1.14
DACTR0: DPOT.3 (SCL), JP2.3
DACTR1: DPOT.4 (SDA), JP2.4
EXT_SUPPLY: LOGIC_IN.17, LOGIC_SUPPLY_SEL.1
GND: ADC1.2 (AGND_2), ADC1.5 (AGND_3), ADC1.7 (VIN_GND), ADC1.8 (AGND_4), ADC1.11 (AGND), ADC1.17 (DR_GND), ADC2.2 (AGND_2), ADC2.5 (AGND_3), ADC2.7 (VIN_GND), ADC2.8 (AGND_4), ADC2.11 (AGND), ADC2.17 (DR_GND), AMP3.11 (V-), BNC1.2 (GND), BNC2.2 (GND), C2.-, C4.+, C5.-, C6.-, C9.2, C10.2, C13.2, C14.1, C15.1, C16.2, C17.1, C19.2, C20.2, C23.2, C24.2, C25.2, C26.2, C27.2, C28.2, C31.2, C32.2, C33.-, C43.-, C44.2, C46.-, C47.2, C49.2, C50.2, C56.2, C60.-, C61.2, C63.2, C70.2, C77.2, CLKBUF.4 (GND), D1.A, D7.A, D11.C, DAC.1 (GND), DPOT.2 (VSS), JP1.28, JP2.28, LOGIC_IN.18, OSC.2 (GND), R8.1, R12.1, R13.2, R16.1, R18.2, R20.1, R27.1, R29.1, R31.1, R34.1, R55.1, R59.2, R60.1, R61.2, R65.2, R66.1, SUPPLY.2 (GND), T1.2 (E), T2.2 (E), T3.2 (E), T4.2 (E), TXRX.4 (GND), TXRX.10 (GND), TXRX.15 (GND), TXRX.21 (GND), TXRX.28 (GND), TXRX.34 (GND), TXRX.39 (GND), TXRX.45 (GND), VREG.3 (GND)
HF_IN: 1REL_A.5, 1REL_A.6, C29.1 (E), R32.2
HF_IN1: 2REL_A.5, 2REL_A.6, C21.1 (E), R17.2
LOGIC_SUPPLY: C60.+, C77.1, LOGIC_SUPPLY_SEL.2, LOGIC_SUPPLY_SEL.4, TXRX.7 (VCC), TXRX.18 (VCC)
unnamed: R1.2, VREG.2 (CAP+)
unnamed: OFFSET1.2 (S), R22.2
unnamed: CLKBUF.2 (OE), R3.2
unnamed: C1.-, VREG.4 (CAP-)
unnamed: CLKBUF.1 (CLKIN), OSC.3 (FO)
unnamed: 2REL_A.1 (O), C18.2
unnamed: AMP2.1 (OUT), D7.C, R4.1, R50.2
unnamed: C1.+, R1.1
unnamed: CLKBUF.7 (1Y2), R7.2
unnamed: OFFSET1.1 (E), R23.1
unnamed: OFFSET1.3 (A), R24.2
unnamed: AMP1.1 (OUT), D1.C, R6.2, R11.1
unnamed: AMP1.4 (-IN), R11.2, R22.1
unnamed: R9.1, R26.1, SUPPLY.4 (FB)
unnamed: DPOT.5 (W), R26.2
unnamed: LOGIC_SUPPLY_SEL.3, R9.2, SUPPLY.5 (OUT)
unnamed: AMP3.9 (-IN), C7.2, R59.1, R62.2
unnamed: R15.2, R16.2, T3.1 (B)
unnamed: OFFSET2.2 (S), R5.2
unnamed: AMP2.4 (-IN), R4.2, R5.1
unnamed: OFFSET2.1 (E), R10.1
unnamed: ADC1.9 (VRM), C49.1
unnamed: ADC1.6 (VIN), C10.1, R6.1
unnamed: OFFSET2.3 (A), R14.2
unnamed: AMP3.13 (-IN), C12.2, R8.2, R57.2
unnamed: 2REL_B.10 (S), C21.2 (A), C22.1 (E), R17.1, R28.2
unnamed: ADC1.18 (VDR), C6.+, C47.1, R21.1
unnamed: 1REL_B.10 (S), C29.2 (A), C30.1 (E), R32.1, R33.2
unnamed: 1REL_B.5, 1REL_B.6, AMP1.3 (+IN), D10.3 (AC)
unnamed: 1REL_B.9 (2), D8.A, T4.3 (C)
unnamed: R25.2, R27.2, T4.1 (B)
unnamed: 1REL_A.1 (O), C73.1
unnamed: 2REL_B.5, 2REL_B.6, AMP2.3 (+IN), D9.3 (AC)
unnamed: R2.1, VREG.6 (REF)
unnamed: 2REL_B.9 (2), D4.A, T3.3 (C)
unnamed: C3.1, C4.-, D11.A, R30.1, R31.2, R35.2, VREG.5 (VOUT)
unnamed: 2REL_B.1 (O), C22.2 (A), C23.1, R28.1, R29.2
unnamed: C3.2, R2.2, R30.2, VREG.1 (FB)
unnamed: 1REL_B.1 (O), C28.1, C30.2 (A), R33.1, R34.2
unnamed: ADC1.22 (D0), RN1.1
unnamed: ADC1.21 (D1), RN1.2 (1)
unnamed: ADC1.20 (D2), RN1.3 (1)
unnamed: ADC2.9 (VRM), C63.1
unnamed: ADC2.6 (VIN), C9.1, R50.1
unnamed: ADC2.18 (VDR), C5.+, C61.1, R45.1
unnamed: ADC1.19 (D3), RN1.4 (1)
unnamed: ADC1.16 (D4), RN2.1
unnamed: ADC1.15 (D5), RN2.2 (1)
unnamed: ADC1.14 (D6), RN2.3 (1)
unnamed: ADC1.13 (D7), RN2.4 (1)
unnamed: ADC2.22 (D0), RN3.1
unnamed: ADC2.21 (D1), RN3.2 (1)
unnamed: C70.1, DAC.2 (REFA), DAC.3 (REFB), DAC.4 (REFC), DAC.5 (REFD), R54.1, R55.2
unnamed: ADC2.20 (D2), RN3.3 (1)
unnamed: ADC2.19 (D3), RN3.4 (1)
unnamed: AMP3.2 (-IN), C11.1, R18.1, R19.2
unnamed: ADC2.16 (D4), RN4.1
unnamed: ADC2.15 (D5), RN4.2 (1)
unnamed: 1REL_A.10 (S), BNC1.1, C73.2
unnamed: AMP3.6 (-IN), C8.1, R61.1, R63.2
unnamed: ADC2.14 (D6), RN4.3 (1)
unnamed: ADC2.13 (D7), RN4.4 (1)
unnamed: 1REL_A.9 (2), D5.A, T1.3 (C)
unnamed: R13.1, R56.2, T1.1 (B)
unnamed: 2REL_A.10 (S), BNC2.1, C18.1
unnamed: 2REL_A.9 (2), D6.A, T2.3 (C)
unnamed: R12.2, R58.2, T2.1 (B)
TR0: JP2.8, TXRX.25 (2!OE)
TR1: JP2.7, TXRX.26 (2A8)
TR2: JP2.10, TXRX.27 (2A7)
TR3: JP2.9, TXRX.29 (2A6)
TR4: JP2.12, TXRX.30 (2A5)
TR5: JP2.11, TXRX.32 (2A4)
TR6: JP2.14, TXRX.33 (2A3)
TR7: JP2.13, TXRX.35 (2A2)
TR8: JP2.16, TXRX.36 (2A1)
TR9: JP2.15, TXRX.37 (1A8)
TR10: JP2.18, TXRX.38 (1A7)
TR11: JP2.17, TXRX.40 (1A6)
TR12: JP2.20, TXRX.41 (1A5)
TR13: JP2.19, TXRX.43 (1A4)
TR14: JP2.22, TXRX.44 (1A3)
TR15: JP2.21, TXRX.46 (1A2)
TR16: JP2.24, TXRX.47 (1A1)
TR17: JP2.23, TXRX.48 (1!OE)
TR18: JP2.6, TXRX.24 (2DIR)
TR19: JP2.5, TXRX.1 (1DIR)
TRIN0: LOGIC_IN.1, TXRX.2 (1B1)
TRIN1: LOGIC_IN.2, TXRX.3 (1B2)
TRIN2: LOGIC_IN.3, TXRX.5 (1B3)
TRIN3: LOGIC_IN.4, TXRX.6 (1B4)
TRIN4: LOGIC_IN.5, TXRX.8 (1B5)
TRIN5: LOGIC_IN.6, TXRX.9 (1B6)
TRIN6: LOGIC_IN.7, TXRX.11 (1B7)
TRIN7: LOGIC_IN.8, TXRX.12 (1B8)
TRIN8: LOGIC_IN.9, TXRX.13 (2B1)
TRIN9: LOGIC_IN.10, TXRX.14 (2B2)
TRIN10: LOGIC_IN.11, TXRX.16 (2B3)
TRIN11: LOGIC_IN.12, TXRX.17 (2B4)
TRIN12: LOGIC_IN.13, TXRX.19 (2B5)
TRIN13: LOGIC_IN.14, TXRX.20 (2B6)
TRIN14: LOGIC_IN.15, TXRX.22 (2B7)
TRIN15: LOGIC_IN.16, TXRX.23 (2B8)
V-: AMP1.2 (V-), AMP2.2 (V-), C24.1, C25.1, C31.1, C32.1, D9.1 (A), D10.1 (A), R14.1, R24.1, R35.1

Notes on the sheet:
Analog input and ADC
Power supplies and voltage references
Logic analyzer

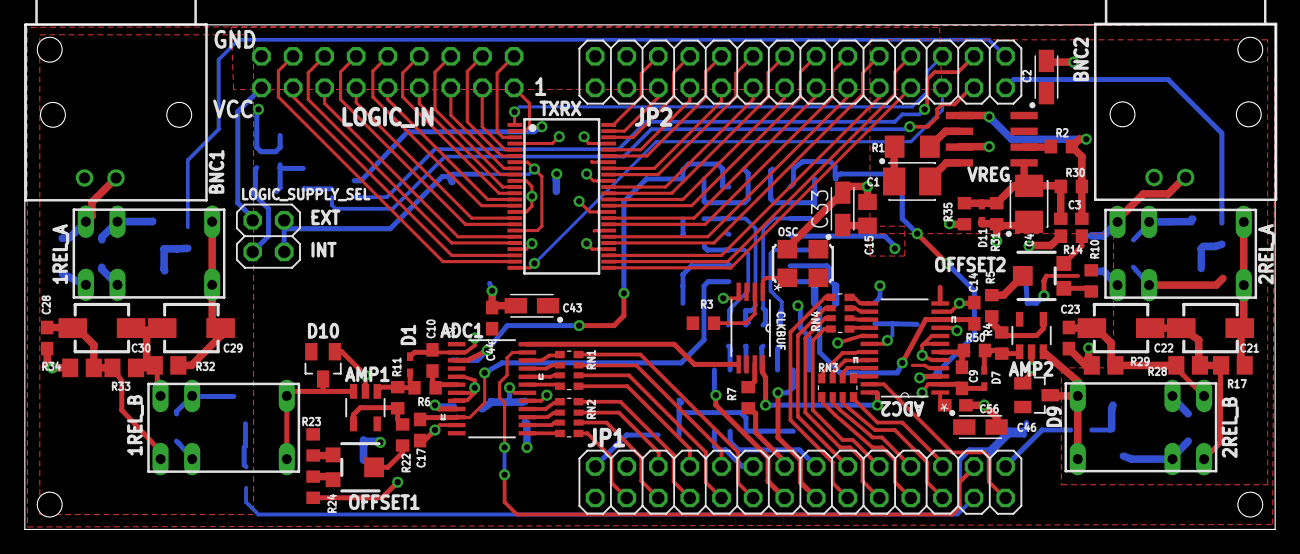
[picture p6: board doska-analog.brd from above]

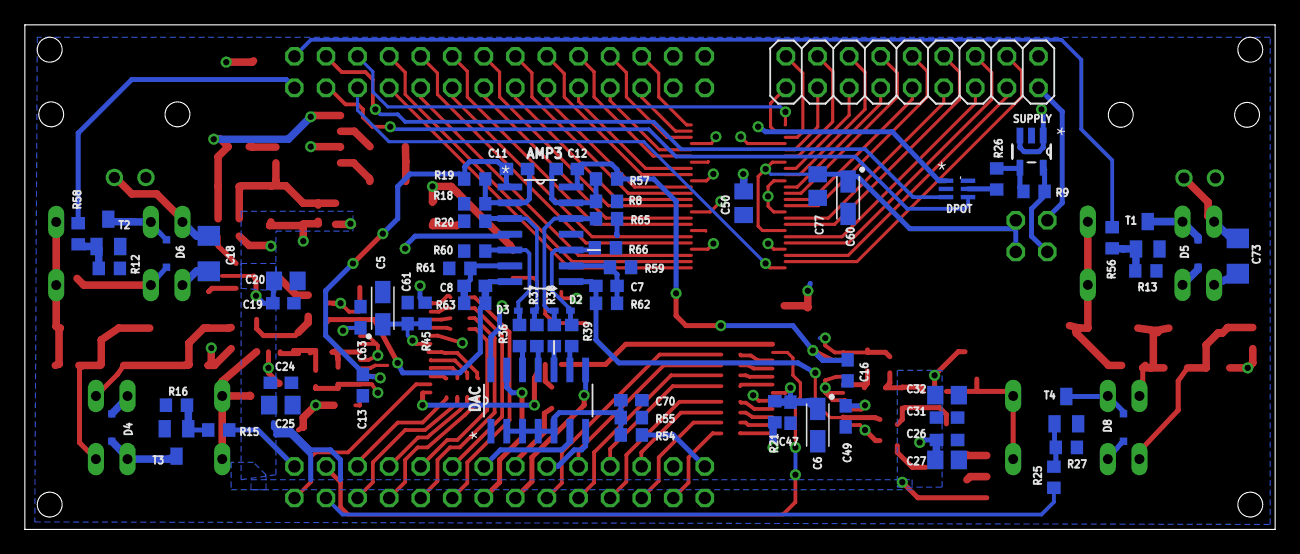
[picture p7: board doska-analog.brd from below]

Board: 2 copper layers, 100.6 x 40.6 mm, 142 parts (71 on the bottom side), 154 nets.

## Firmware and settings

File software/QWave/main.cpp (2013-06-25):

//
//   main.cpp
//   QWave
//   Copyright (c) 2012-2013, Bruno Kremel
//   All rights reserved.
//
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
//    THIS SOFTWARE IS PROVIDED BY Bruno Kremel ''AS IS'' AND ANY
//    EXPRESS OR IMPLIED WARRANTIES, INCLUDING, BUT NOT LIMITED TO, THE IMPLIED
//    WARRANTIES OF MERCHANTABILITY AND FITNESS FOR A PARTICULAR PURPOSE ARE
//    DISCLAIMED. IN NO EVENT SHALL Bruno Kremel BE LIABLE FOR ANY
//    DIRECT, INDIRECT, INCIDENTAL, SPECIAL, EXEMPLARY, OR CONSEQUENTIAL DAMAGES
//    (INCLUDING, BUT NOT LIMITED TO, PROCUREMENT OF SUBSTITUTE GOODS OR SERVICES;
//    LOSS OF USE, DATA, OR PROFITS; OR BUSINESS INTERRUPTION) HOWEVER CAUSED AND
//    ON ANY THEORY OF LIABILITY, WHETHER IN CONTRACT, STRICT LIABILITY, OR TORT
//    (INCLUDING NEGLIGENCE OR OTHERWISE) ARISING IN ANY WAY OUT OF THE USE OF THIS
//    SOFTWARE, EVEN IF ADVISED OF THE POSSIBILITY OF SUCH DAMAGE.

#include "MyApplication.h"
#include "GUI/Window.h"
#include "Exceptions/Exception.h"
#include <QString>

/**
 * @brief main Opens Qt application loop by return app.exec()
 * @param argc
 * @param argv
 * @return
 */
int main(int argc, char *argv[])
{
    //QApplication app(argc, argv);
    MyApplication app(argc, argv);
    Window window;
    app.setAlertWidget(&window);
    window.show();
    return app.exec();
}

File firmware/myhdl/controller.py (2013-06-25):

#
#   This file is part of QWave firmware. 
#   Copyright (c) 2012-2013, Bruno Kremel
#   All rights reserved.
#
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
#    THIS SOFTWARE IS PROVIDED BY Bruno Kremel ''AS IS'' AND ANY
#    EXPRESS OR IMPLIED WARRANTIES, INCLUDING, BUT NOT LIMITED TO, THE IMPLIED
#    WARRANTIES OF MERCHANTABILITY AND FITNESS FOR A PARTICULAR PURPOSE ARE
#    DISCLAIMED. IN NO EVENT SHALL Bruno Kremel BE LIABLE FOR ANY
#    DIRECT, INDIRECT, INCIDENTAL, SPECIAL, EXEMPLARY, OR CONSEQUENTIAL DAMAGES
#    (INCLUDING, BUT NOT LIMITED TO, PROCUREMENT OF SUBSTITUTE GOODS OR SERVICES;
#    LOSS OF USE, DATA, OR PROFITS; OR BUSINESS INTERRUPTION) HOWEVER CAUSED AND
#    ON ANY THEORY OF LIABILITY, WHETHER IN CONTRACT, STRICT LIABILITY, OR TORT
#    (INCLUDING NEGLIGENCE OR OTHERWISE) ARISING IN ANY WAY OUT OF THE USE OF THIS
#    SOFTWARE, EVEN IF ADVISED OF THE POSSIBILITY OF SUCH DAMAGE.

from myhdl import *

#command codes
RESET              = 0xAE                
SET_VREF           = 0x10                 
SET_VLOG           = 0x11               
SET_ATTENUATORS    = 0x20                
SET_COUPLINGS      = 0x21             
SET_DECIMATION     = 0x30            
SET_ANALOGTRIGGER  = 0x31         
SET_DIGITALTRIGGER = 0x32                      
START_CAPTURE      = 0x40

CLEANUP = 0xAA
#responses
DATA_DUMP          = 0x50
DATA_OK            = 0x80
DATA_BAD           = 0x90

tCtrlStates = enum('INIT0', 'INIT1', 'IDLE', 'SET_VREF0', 'SET_VREF1', 'SET_VLOG0', 
                   'SET_VLOG1', 'SET_ATTENUATORS', 'SET_COUPLINGS', 'SET_DECIMATION', 
                   'SET_ANALOGTRIGGER', 'SET_DIGITALTRIGGER', 'DUMP_DATA_INT1', 'DUMP_DATA_INT2',
                   'DUMP_DATA0', 'DUMP_DATA1', 'DUMP_DATA2', 'DUMP_DATA3', 'DUMP_DATA4', 'DUMP_DATA_PREPFT', 
                   'START_CAPTURE', 'CAPTURE', 'READ_COMMAND', 'READ_CMD_DATA', 'DECODE_CMD', 
                   'REQUEST_RESEND0', 'REQUEST_RESEND1', 'REQUEST_RESEND2', 'SEND_ACKNOWLEDGE0',
                   'SEND_ACKNOWLEDGE1', 'SEND_ACKNOWLEDGE2', 'PREPARE_ADC')

def controller(clk, reset, ft245din, ft245dout, ft245rw, ft245busy, ft245oe, ft245wr,
               ft245dataWaitIn, ft245dataWaitOut, ft245strobe, ft245reset, dacReset, 
               dacVrefTopA, dacVrefTopB, dacVrefBotA, dacVrefBotB, dacStrobe, dacBusy,
               digipotReset, digipotValue, digipotStrobe, digipotBusy, bufferReset, 
               bufferDataOut, bufferDataIn, bufferReady, bufferOutputInputReady, 
               bufferAllowWriteOverlap, bufferDataDirection, decimatorNewValueFlag,
               decimationRatioBase, decimationStyle, decimator1out, decimator2out,
               trigger1Type, trigger1Slope, analogTrigger1Reset, trigger1Value,
               analog1Trigger, trigger2Type, trigger2Slope, analogTrigger2Reset,
               trigger2Value, analog2Trigger, digitalTriggerReset, triggerPattern, 
               triggerSamples, digiTrigger, adc1pd, adc2pd, adc1relatt, adc2relatt, 
               adc1relco, adc2relco, led0, led1, logicAnalyzer, la1dir, la2dir, la1oe, la2oe, fastClk):
    """
    Main DSO controller.
    clk - clock 60MHz from FTDI
    reset - asynchronous reset
    ft245* respective FT245 interfaces
    dac* respective dac interfaces
    digipot* respective digipot interfaces
    buffer* respective buffer interfaces
    decim* respective decimators interfaces
    trigger* triggers interfaces
    adc1pd - power down of ADC1
    adc2pd - power down of ACC2
    adc1relatt - relay of ADC1 attenuator
    adc2relatt - relay of ADC2 attenuator
    adc1relco - relay of ADC1 coupling
    adc2relco - relay of ADC2 coupling
    led0 - info LED 0
    led1 - info LED 1
    logicAnalyzer - data from logic analyzer decimator
    la* interface of logic analyzer transciever
    fastClk - 125MHz clock from ADC oscillator
    
    Commnnication protocol:
     Commands:
     Bit lengths        | 8bit                 | 72bit     |   
     Field description  | Message number       | Data      | 

     RESET              | 0x00                 | DON'T CARE
     SET_VREF           | 0x10                 | 8bit - TopA, 8bit - BotA, 8bit - TopB, 8bit - BotB
     SET_VLOG           | 0x11                 | 8bit - 7bit - value
     SET_ATTENUATORS    | 0x20                 | 8bit - 1bit - att. relay ADC1, 8bit - 1bit att. relay ADC2
     SET_COUPLINGS      | 0x21                 | 1bit - ac/dc relay ADC1, 1bit ac/dc relay ADC2
     SET_DECIMATION     | 0x30                 | 8bit - 4bit - decimationRatioBase, 8bit -2bit - decimationStyle
     SET_ANALOGTRIGGER  | 0x31                 | Trigger adc1: 8bit - value, 8bit -  1bit - triggerType, 1bit - slope | 
                                                 Trigger adc2: 8bit - value, 8bit - 1bit - triggerType, 1bit - slope
     SET_DIGITALTRIGGER | 0x32                 | 64bit - pattern, 2bit - samples
     START_CAPTURE      | 0x40                 | 8bit - channel selection
                                                 0x00 - analog1 only, 0x01 analog2 only, 0x02 analog1 + digi,
                                                 0x03 - analog2 + digi, 0x04 analog1+analog2, 0x05 an1+an2+dig
                                                 0x06 - dig only
     Respones:
     DATA_DUMP          | 0x50                 | burst of data (longer than 72bit) where first two bytes are respective ADC data and
                                                 second two bytes are data of logic analyzer
     DATA_OK            | 0x80                 | DON'T CARE
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

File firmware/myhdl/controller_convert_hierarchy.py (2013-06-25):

#
#   This file is part of QWave firmware. 
#   Copyright (c) 2012-2013, Bruno Kremel
#   All rights reserved.
#
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
#    THIS SOFTWARE IS PROVIDED BY Bruno Kremel ''AS IS'' AND ANY
#    EXPRESS OR IMPLIED WARRANTIES, INCLUDING, BUT NOT LIMITED TO, THE IMPLIED
#    WARRANTIES OF MERCHANTABILITY AND FITNESS FOR A PARTICULAR PURPOSE ARE
#    DISCLAIMED. IN NO EVENT SHALL Bruno Kremel BE LIABLE FOR ANY
#    DIRECT, INDIRECT, INCIDENTAL, SPECIAL, EXEMPLARY, OR CONSEQUENTIAL DAMAGES
#    (INCLUDING, BUT NOT LIMITED TO, PROCUREMENT OF SUBSTITUTE GOODS OR SERVICES;
#    LOSS OF USE, DATA, OR PROFITS; OR BUSINESS INTERRUPTION) HOWEVER CAUSED AND
#    ON ANY THEORY OF LIABILITY, WHETHER IN CONTRACT, STRICT LIABILITY, OR TORT
#    (INCLUDING NEGLIGENCE OR OTHERWISE) ARISING IN ANY WAY OUT OF THE USE OF THIS
#    SOFTWARE, EVEN IF ADVISED OF THE POSSIBILITY OF SUCH DAMAGE.

from myhdl import *

from controller import controller
from decimator import decimator
from digital_decimator import digital_decimator
from buff import buff
from digipot_controller import digipot_controller
from dac_controller import dac_controller
from ft245sync import ft245sync
from trigger_analog import trigger_analog
from trigger_digital import trigger_digital
from decimator_clock_divisor import decimator_clock_divisor

import sys
sys.setrecursionlimit(10000)

PERIOD = 6
PERIOD_FTDI = 16

HALF_PERIOD = PERIOD//2
HALF_PERIOD_FTDI = PERIOD_FTDI//2

LFSR_SEED = 468
LFSR_WIDTH = 10

MAXIMAL_RATIO = 2**8

#include or exclude testbench
INCLUDE_TESTBENCH = True

def convert_modules():
    clock = Signal(bool(False))
    clockFtdi = Signal(bool(False))
    reset = Signal(bool(False))
    
    decimatorNewValueFlag = Signal(bool(False))
    ft245din = Signal(intbv(0)[8:])
    ft245dout = Signal(intbv(0)[8:])
    ft245rw = Signal(bool(False))
    ft245clock = Signal(bool(False))
    ft245reset = Signal(bool(False))
    ft245busy = Signal(bool(False))
    ft245oe = Signal(bool(False))
    ft245wr = Signal(bool(False))
    ft245dataWaitIn = Signal(bool(False))
    ft245dataWaitOut = Signal(bool(False))
    ft245strobe = Signal(bool(False))
    dacReset = Signal(bool(False))
    dacBusy = Signal(bool(False))
    dacStrobe = Signal(bool(False))
    dacVrefTopA = Signal(intbv(0)[8:])
    dacVrefTopB = Signal(intbv(0)[8:])
    dacVrefBotA = Signal(intbv(0)[8:])
    dacVrefBotB = Signal(intbv(0)[8:])
    digipotValue = Signal(intbv(0)[7:])
    digipotReset = Signal(bool(False))
    digipotBusy = Signal(bool(False))
    digipotStrobe = Signal(bool(False))
    bufferclock = Signal(bool(False))
    bufferReset = Signal(bool(False))
    bufferDataIn = Signal(intbv(0)[32:])
    bufferDataOut = Signal(intbv(0)[32:])
    bufferReady = Signal(bool(False))
    bufferOutputInputReady = Signal(bool(False))
    bufferAllowWriteOverlap = Signal(bool(False))
    bufferUseSdram = Signal(bool(False))
    bufferDataDirection = Signal(bool(False))
    decimatorclockOut = Signal(bool(False))
    decimationRatioBase = Signal(intbv(0, min = 0, max = 9))
    decimationStyle = Signal(intbv(0)[2:])
    analogTrigger1Reset = Signal(bool(False))
    trigger1Type = Signal(bool(False))
    trigger1Slope = Signal(bool(False))
    analog1Trigger = Signal(bool(False))
    trigger1Value = Signal(intbv(0)[8:])
    analogTrigger2Reset = Signal(bool(False))
    trigger2Type = Signal(bool(False))
    trigger2Slope = Signal(bool(False))
    analog2Trigger = Signal(bool(False))
    trigger2Value = Signal(intbv(0)[8:])
    digitalTriggerReset = Signal(bool(False))
    digiTrigger = Signal(bool(False))
    triggerPattern = Signal(intbv(0)[64:])
    triggerSamples = Signal(intbv(0, min = 0, max = 4))
    decimator1out = Signal(intbv(0)[8:])
    decimator2out = Signal(intbv(0)[8:])
    decimator1in = Signal(intbv(0)[8:])
    decimator2in = Signal(intbv(0)[8:])
    adc1pd = Signal(bool(False))
    adc2pd = Signal(bool(False))
    adc1relatt = Signal(bool(False))
    adc2relatt = Signal(bool(False))
    adc1relco = Signal(bool(False))
    adc2relco = Signal(bool(False))
    led0 = Signal(bool(False))
    led1 = Signal(bool(False))
    logicAnalyzer = Signal(intbv(0)[16:])
    logicAnalyzer_dec = Signal(intbv(0)[16:])
    la1dir = Signal(bool(False))
    la2dir = Signal(bool(False))
    la1oe  = Signal(bool(False))
    la2oe  = Signal(bool(False))
    decimationRatio = Signal(intbv(0, min = 0, max = MAXIMAL_RATIO+1))
    alwaysEn  = Signal(bool(False))
    
    decimator1clockOut = Signal(bool(False))
    decimator2clockOut = Signal(bool(False))
    decimatorDigClockOut = Signal(bool(False))
    
    serialOut = Signal(bool(False))
    load = Signal(bool(False))
    ldac = Signal(bool(False))
    clkDacOut = Signal(bool(False))
    
    sda = TristateSignal(bool(False))
    scl = TristateSignal(bool(False))
    sda_d = sda.driver()
    scl_d = scl.driver()
    sda_dpull = sda.driver()
    scl_dpull = scl.driver()
    
    rxf = Signal(bool(False))
    txe = Signal(bool(False))
    rd = Signal(bool(False))
    wr = Signal(bool(False))
    siwu = Signal(bool(False))
    adbus = TristateSignal(intbv(0)[8:])
    
    print("Converting decimator_clock_divisor")
    toVHDL(decimator_clock_divisor, clock, reset, decimationRatioBase, decimationRatio, decimator2clockOut, decimatorNewValueFlag, alwaysEn)
    print("Converting: buffer")
    toVHDL(buff, clock, bufferReset, bufferDataIn, bufferDataOut, bufferReady, bufferOutputInputReady, 
                        bufferAllowWriteOverlap, bufferDataDirection, decimator2clockOut, clockFtdi, alwaysEn)
    print("Converting: ft245sync")
    toVHDL(ft245sync, clockFtdi, ft245reset, rxf, txe, rd, wr, ft245oe, siwu, adbus, ft245din, ft245dout, 
                               ft245rw, ft245busy, ft245dataWaitIn, ft245dataWaitOut, ft245strobe)
    print("Converting: digipot_controller")
    toVHDL(digipot_controller, clock, digipotReset, digipotValue, digipotStrobe, digipotBusy, sda, scl)
    print("Converting: dac_controller")
    toVHDL(dac_controller, clock, dacReset, dacVrefTopA, dacVrefTopB, dacVrefBotA, dacVrefBotB, dacStrobe, 
                                       serialOut, load, ldac, clkDacOut, dacBusy)
    print("Converting: trigger_digital")
    toVHDL(trigger_digital, clock, digitalTriggerReset, logicAnalyzer, triggerPattern, triggerSamples, digiTrigger, decimator2clockOut, alwaysEn)
    print("Converting: trigger_analog")
    toVHDL(trigger_analog, clock, analogTrigger2Reset, decimator2out, 
                                        trigger2Type, trigger2Slope, trigger2Value, analog2Trigger, decimator2clockOut, alwaysEn)
    print("Converting: decimator")
    toVHDL(decimator, clock, reset, decimator1in, decimator2out, decimationRatio,  decimationRatioBase, decimationStyle, decimator2clockOut, decimatorNewValueFlag)
    print("Converting: digital_decimator")
    toVHDL(digital_decimator, clock, reset, logicAnalyzer, logicAnalyzer_dec, decimationRatio, decimatorDigClockOut)
    print("Converting: controller")
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

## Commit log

2013-06-25 Initial commit of QWave project
    [doska-analog.brd, doska-analog.sch, doska-digital.brd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]
2013-06-26 Fixed short of internal layers on digital board (eagle bug).
    [doska-digital.brd, doska-digital.sch]
2013-06-26 added link to PDF schematics
